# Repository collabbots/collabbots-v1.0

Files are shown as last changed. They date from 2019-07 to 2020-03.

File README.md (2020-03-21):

# collabbots-v1.0



Pictures of the setup (July 2019):
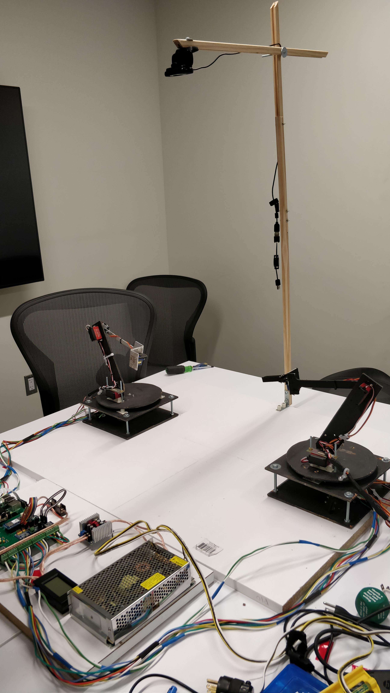
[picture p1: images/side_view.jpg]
side_view

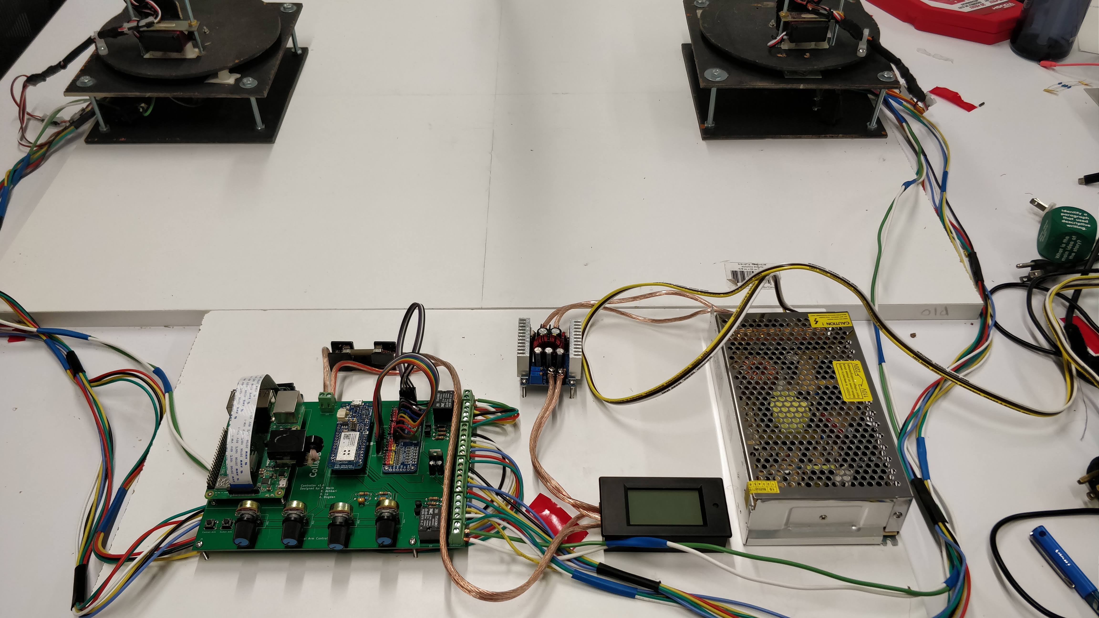
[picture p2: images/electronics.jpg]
electronics

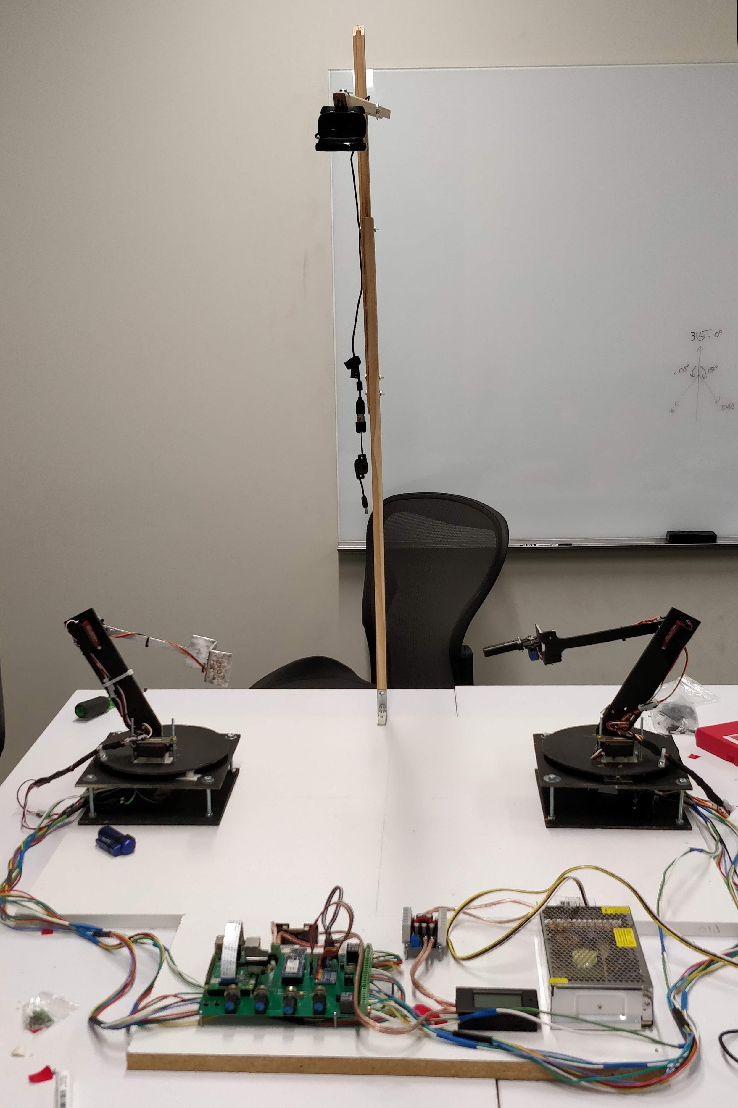
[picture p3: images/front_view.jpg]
front_view


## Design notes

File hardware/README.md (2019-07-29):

# hardware
Wiring diagrams, PCBs, and CAD files for the robots' hardware

**Controller PCB**
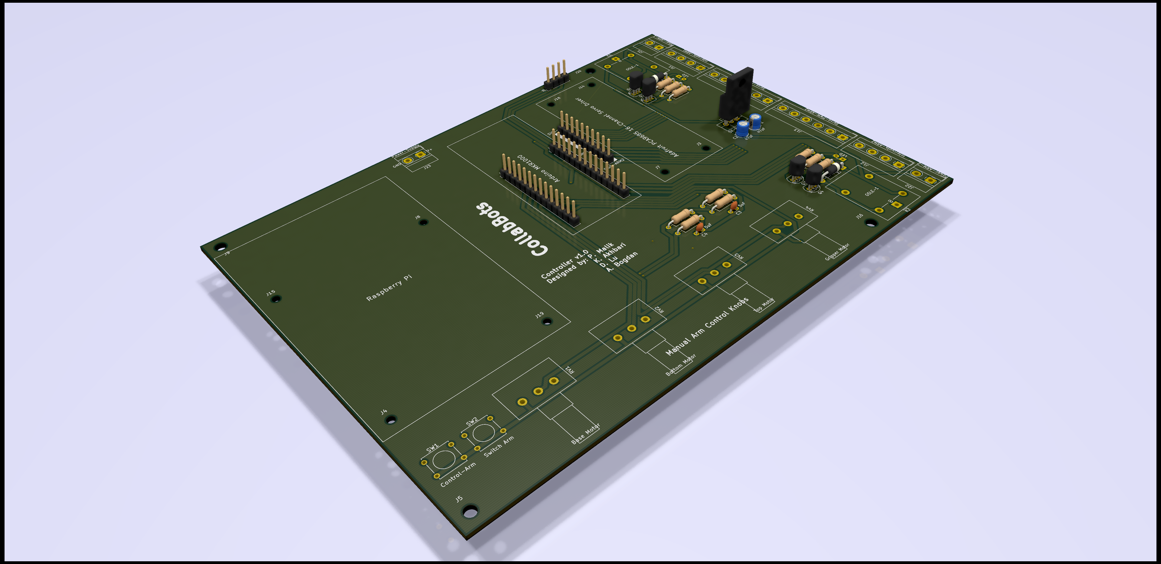
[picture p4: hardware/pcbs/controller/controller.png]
controller


**Connection Portal PCB**
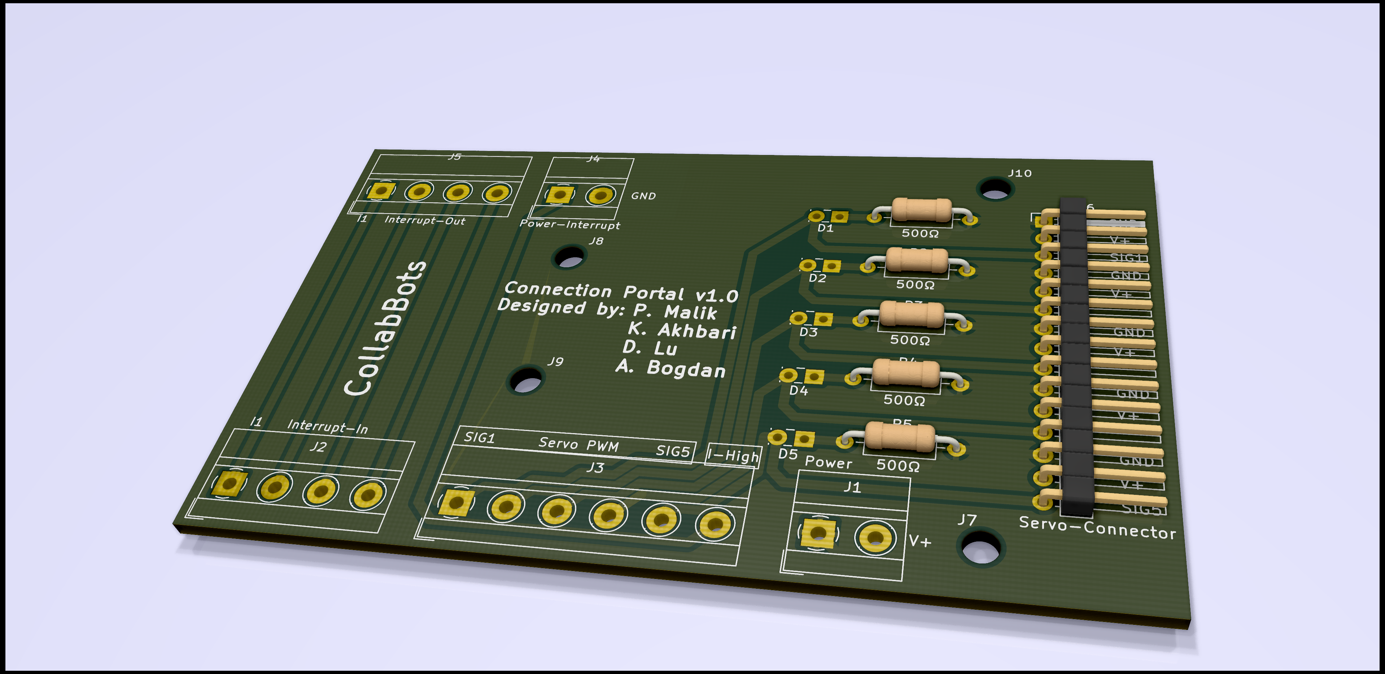
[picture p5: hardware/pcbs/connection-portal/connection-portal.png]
connection-portal


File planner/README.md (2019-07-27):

# planner
Plans and controls the tasks each robot has to perform to achieve its goal, based on inputs from the vision module.
1. The kinematics module solves the forward and inverse kinematics for the 3DOF Collabbots arm. It also handles visualization 
of the arm state.
2. The trajectory module solves/updates the trajectory for an arm  on the fly (real-time) based on inputs about obstacles in space from the vision module, with predictive planning of dynamic obstacles like another robotic arm. This module does not need or take information about the other arm(s) from the driver or kinematics module, and is just based on vision for that purpose.
3. The visualization module displays the current state of the system, the planned trajectories of the robotic arms, and status of the structure being built by the robots.

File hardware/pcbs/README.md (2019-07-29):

**Lessons learned**

Possible improvements for v2.0/v1.0 Rev B of the pcbs:

1. Reverse voltage protection using power PMOS, [zener, resistor (and LED for indication)]. **(vv important)**
2. integration of PCA9685 circuit into the pcb itself: reduce form factor and external wiring. **(vv important)**
3. For the connection portal pcb: the interrupt wires have to currently be all powered through one I-High and GND port. Rather have an array of 3 jumpers: interrupt, power, GND so that it is easier to wire and manage micro/limit switches. **(important)**
4. Use bigger (appropriately sized) vias -- comparable to the track thickness
5. Make the LED circuits brighter -- use transistors
6. Make an enclosure for the pcbs, with place for the knobs to come out.
7. Properly label all connections and components on the pcb (both sides for clarity and ease of use)
8. The number of motors is 4, but the connection portal and controller have capacity and connections for 5. This is a mismatch; keep the limit of motors to 4 if the arm design remains the same.
9. Have a port for the switch, which will interrupt the input power. This can be done by having a mount for a fuse between the switch and input power, so that traces don't have to be very thick and instead GND can go through the fuse from the switch. **(vv important)**
10. Have a dedicated place to mount the buck converter output fuse on the controller which could be a thick screw terminal, maybe. **(important)** 
11. The V+ and GND plates act like a capacitor and is dangerous for sensitive equipment or devices monitoring V+ since even after cutting the supply, V+ is floating at 1.5V or higher. Design circuitry to discharge this without overloading the supply and overheating when switched on. **(important)**
12. Arrange the terminal block for the two arms so that it is easier to wire them. one on left and the other on right.
13. Can mount the RPi on the bottom, thereby reducing the PCB footprint by a lot, and also allowing enough space for routing cables for the RPi.
14. Try using SMD components to further reduce the footprint.
15. Can have LED indicators for all the wires for visual debugging and also. Use the on-board 5V supply for that.
16. Try redesigning the pcb such that the design is completely modular. Another controller pcb can add two more arms at maximum. Therefore removing RPi from the board and having it has an optional mount is one step towards achieving this. **(vvv important)**
17. Servo zero set correction circuitry (try adding large capacitors on the output -- make sure to avoid high current surges). **(vv important)**
18. The connection portal will not be necessary if we handle each robot using a small microcontroller. This will also enable parallel control. So, just a USB cable and power supply goes into the robot -- also reduces wiring tremendously.
19. There can be a USB interface board that handles distributing serial commands to multiple robots. So, from a single USB port of the RPi/computer, you have a command handler PCB connected to multiple robots through USB ports. This will promote expandibility of the system.

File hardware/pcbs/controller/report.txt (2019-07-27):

Info: Processing component “J19:/5D1BA1C7:MountingHole:MountingHole_2.2mm_M2”.
Info: Processing component “Q3:/5D0CD34E:Package_TO_SOT_THT:TO-92_Inline”.
Info: Processing component “Q2:/5D0ABB15:Package_TO_SOT_THT:TO-92_Inline”.
Info: Processing component “Q1:/5D03D092:Package_TO_SOT_THT:TO-92_Inline”.
Info: Processing component “K2:/5D0CD348:Relay_THT:Relay_SPDT_Omron-G5LE-1”.
Info: Processing component “K1:/5D09949D:Relay_THT:Relay_SPDT_Omron-G5LE-1”.
Info: Processing component “J22:/5D17306D:TerminalBlock_MetzConnect:TerminalBlock_MetzConnect_Type011_RT05502HBWC_1x02_P5.00mm_Horizontal”.
Info: Processing component “J21:/5D03C864:TerminalBlock_MetzConnect:TerminalBlock_MetzConnect_Type011_RT05502HBWC_1x02_P5.00mm_Horizontal”.
Info: Processing component “J20:/5D1C3773:MountingHole:MountingHole_3.2mm_M3”.
Info: Processing component “Q4:/5D0CD33C:Package_TO_SOT_THT:TO-92_Inline”.
Info: Processing component “J18:/5D1B0969:MountingHole:MountingHole_2.2mm_M2”.
Info: Processing component “J17:/5D10BA03:Connector_PinHeader_2.54mm:PinHeader_1x10_P2.54mm_Vertical”.
Info: Processing component “J16:/5D1C1334:MountingHole:MountingHole_3.2mm_M3”.
Info: Processing component “J15:/5D1B7D51:MountingHole:MountingHole_2.2mm_M2”.
Info: Processing component “J14:/5D1AE1C4:MountingHole:MountingHole_2.2mm_M2”.
Info: Processing component “J13:/5D195D9E:TerminalBlock_MetzConnect:TerminalBlock_MetzConnect_Type011_RT05506HBWC_1x06_P5.00mm_Horizontal”.
Info: Processing component “J12:/5D16642E:TerminalBlock_MetzConnect:TerminalBlock_MetzConnect_Type011_RT05504HBWC_1x04_P5.00mm_Horizontal”.
Info: Processing component “R8:/5D1610A8:Resistor_THT:R_Axial_DIN0207_L6.3mm_D2.5mm_P10.16mm_Horizontal”.
Info: Processing component “SW2:/5D1610C0:Button_Switch_THT:SW_Tactile_Straight_KSL0Axx1LFTR”.
Info: Processing component “SW1:/5D25172B:Button_Switch_THT:SW_Tactile_Straight_KSL0Axx1LFTR”.
Info: Processing component “RV4:/5D0DCB00:Potentiometer_THT:Potentiometer_Alps_RK163_Single_Horizontal”.
Info: Processing component “RV3:/5D0DDD8A:Potentiometer_THT:Potentiometer_Alps_RK163_Single_Horizontal”.
Info: Processing component “RV2:/5D0DBCBA:Potentiometer_THT:Potentiometer_Alps_RK163_Single_Horizontal”.
Info: Processing component “RV1:/5D050ABA:Potentiometer_THT:Potentiometer_Alps_RK163_Single_Horizontal”.
Info: Processing component “R10:/5D12BD6F:Resistor_THT:R_Axial_DIN0207_L6.3mm_D2.5mm_P10.16mm_Horizontal”.
Info: Processing component “R9:/5D135C93:Resistor_THT:R_Axial_DIN0207_L6.3mm_D2.5mm_P10.16mm_Horizontal”.
Info: Processing component “J11:/5D15F505:TerminalBlock_MetzConnect:TerminalBlock_MetzConnect_Type011_RT05504HBWC_1x04_P5.00mm_Horizontal”.
Info: Processing component “R7:/5D17BC5B:Resistor_THT:R_Axial_DIN0207_L6.3mm_D2.5mm_P10.16mm_Horizontal”.
Info: Processing component “R6:/5D0CD35A:Resistor_THT:R_Axial_DIN0207_L6.3mm_D2.5mm_P10.16mm_Horizontal”.
Info: Processing component “R5:/5D0CD336:Resistor_THT:R_Axial_DIN0207_L6.3mm_D2.5mm_P10.16mm_Horizontal”.
Info: Processing component “R4:/5D0CD354:Resistor_THT:R_Axial_DIN0207_L6.3mm_D2.5mm_P10.16mm_Horizontal”.
Info: Processing component “R3:/5D0AFA57:Resistor_THT:R_Axial_DIN0207_L6.3mm_D2.5mm_P10.16mm_Horizontal”.
Info: Processing component “R2:/5D03C157:Resistor_THT:R_Axial_DIN0207_L6.3mm_D2.5mm_P10.16mm_Horizontal”.
Info: Processing component “R1:/5D0ACEB4:Resistor_THT:R_Axial_DIN0207_L6.3mm_D2.5mm_P10.16mm_Horizontal”.
Info: Processing component “J10:/5D191D71:TerminalBlock_MetzConnect:TerminalBlock_MetzConnect_Type011_RT05506HBWC_1x06_P5.00mm_Horizontal”.
Info: Processing component “C1:/5D0EA149:Capacitor_THT:CP_Radial_D4.0mm_P1.50mm”.
Info: Processing component “C2:/5D0EABFE:Capacitor_THT:CP_Radial_D4.0mm_P1.50mm”.
Info: Processing component “C3:/5D1610C6:Capacitor_THT:C_Disc_D3.0mm_W1.6mm_P2.50mm”.
Info: Processing component “C4:/5D11BE1B:”.
Info: Processing component “D1:/5D03DCB9:Diode_THT:D_DO-41_SOD81_P10.16mm_Horizontal”.
Info: Processing component “D2:/5D03B8C7:LED_THT:LED_Rectangular_W3.9mm_H1.8mm_FlatTop”.
Info: Processing component “D3:/5D0CD342:Diode_THT:D_DO-41_SOD81_P10.16mm_Horizontal”.
Info: Processing component “D4:/5D0CD330:LED_THT:LED_Rectangular_W3.9mm_H1.8mm_FlatTop”.
Info: Processing component “J1:/5D042CD9:Connector_PinHeader_2.54mm:PinHeader_1x14_P2.54mm_Vertical”.
Info: Processing component “J2:/5D044DCC:Connector_PinHeader_2.54mm:PinHeader_1x14_P2.54mm_Vertical”.
Info: Processing component “5V-Regulator1:/5D0E8236:Package_TO_SOT_THT:TO-220F-3_Vertical”.
Info: Processing component “J9:/5D1BC6B0:MountingHole:MountingHole_3.2mm_M3”.
Info: Processing component “J8:/5D1B31C7:MountingHole:MountingHole_2.2mm_M2”.
Info: Processing component “J7:/5D0F0557:MountingHole:MountingHole_2.2mm_M2”.
Info: Processing component “J6:/5D1F4AF5:Connector_PinHeader_2.54mm:PinHeader_1x04_P2.54mm_Vertical”.
Info: Processing component “J5:/5D1BEE64:MountingHole:MountingHole_3.2mm_M3”.
Info: Processing component “J4:/5D1B584A:MountingHole:MountingHole_2.2mm_M2”.
Info: Processing component “J3:/5D0F0551:MountingHole:MountingHole_2.2mm_M2”.
Reconnect J2 pin 14 from 5V to D6.
Reconnect J2 pin 1 from D6 to 5V.
Reconnect J2 pin 2 from D7 to VIN.
Reconnect J2 pin 3 from D8-MOSI to Vcc.
Reconnect J2 pin 13 from VIN to D7.
Reconnect J2 pin 12 from Vcc to D8-MOSI.
Reconnect J2 pin 11 from GND to D9-SCK.
Reconnect J2 pin 10 from RESET to D10-MISO.
Reconnect J2 pin 9 from D14-Tx to D11-SDA.
Reconnect J2 pin 8 from D13-Rx to D12-SCL.
Reconnect J2 pin 7 from D12-SCL to D13-Rx.
Reconnect J2 pin 6 from D11-SDA to D14-Tx.
Reconnect J2 pin 5 from D10-MISO to RESET.
Reconnect J2 pin 4 from D9-SCK to GND.

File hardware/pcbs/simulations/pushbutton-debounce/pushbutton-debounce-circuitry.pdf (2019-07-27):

PWL(0 0 0.2 0 0.2009 2 0.2015 3.3 0.2020 2 0.2025 0 0.3 0 0.3001 3.3 0.4 3.3 0.5 3.3 0.6 3.3 0.7 3.3 1 3.3)

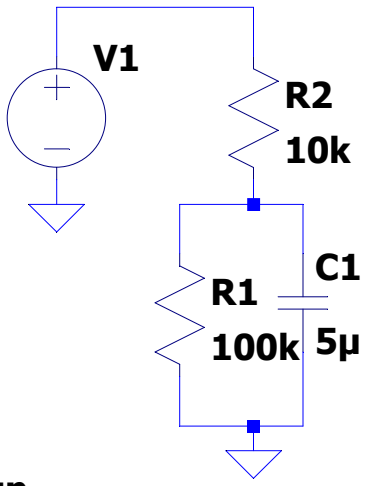
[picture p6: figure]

### .tran 0 0.5 0.19 startup

--- E:\1. Undergraduate Studies\3. Hackathons and Projects\3. Collaborations\CollabBots\hardware\pcbs\simulations\pushbutton-debounce\pushbutton-debounce-circuitry.asc ---

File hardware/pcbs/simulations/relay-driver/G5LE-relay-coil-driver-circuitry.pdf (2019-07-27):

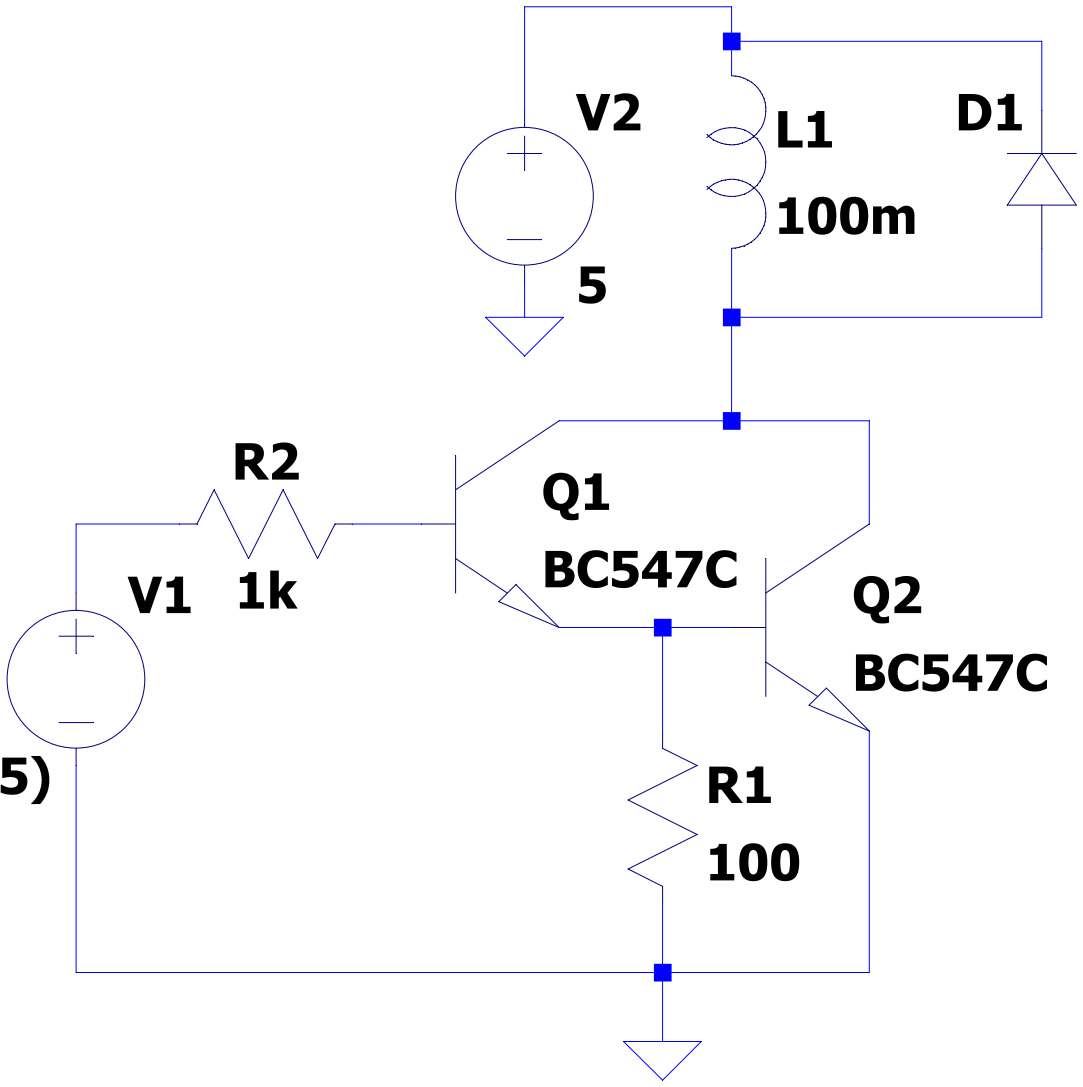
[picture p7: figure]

# PULSE(0 3.3 0 0 0 0.5 1 5)

1N4148

# .tran 0 5 0 startup

--- E:\1. Undergraduate Studies\3. Hackathons and Projects\3. Collaborations\CollabBots\hardware\pcbs\simulations\relay-driver\G5LE-relay-coil-driver-circuitry.asc ---

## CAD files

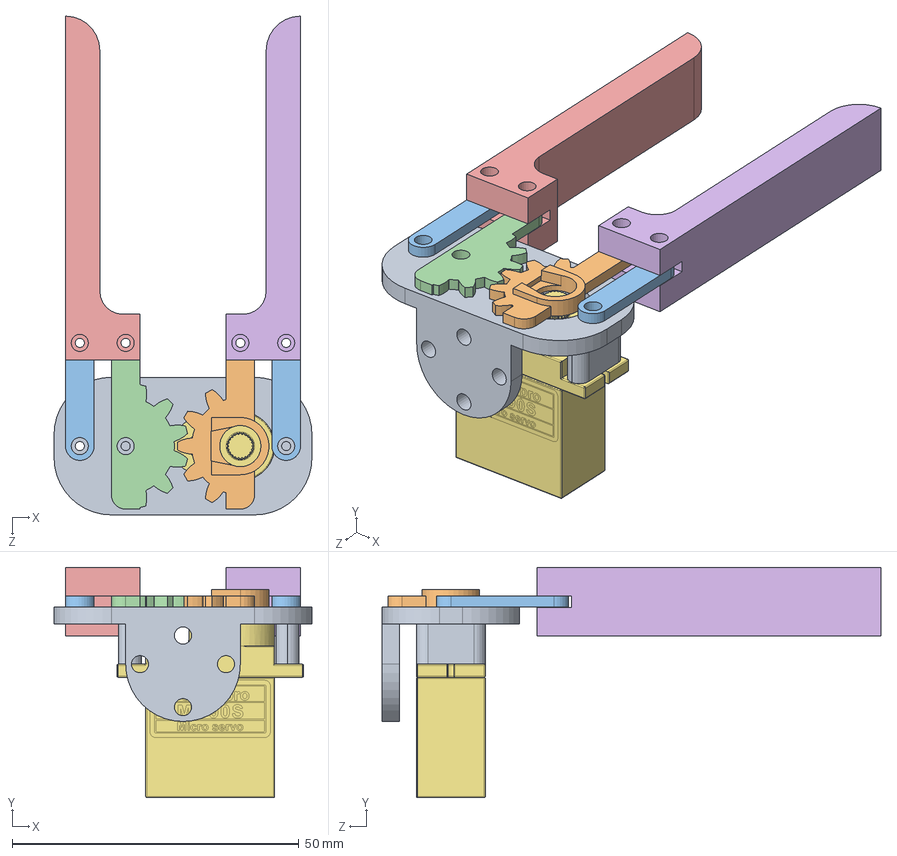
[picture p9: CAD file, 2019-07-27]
hardware/mech/gripper/assembly.SLDASM
45.0 x 40.2 x 87.0 mm
gripper_base
gear_2
bar_1 x 2
gear_1
finger_L
finger_R
micro_servo

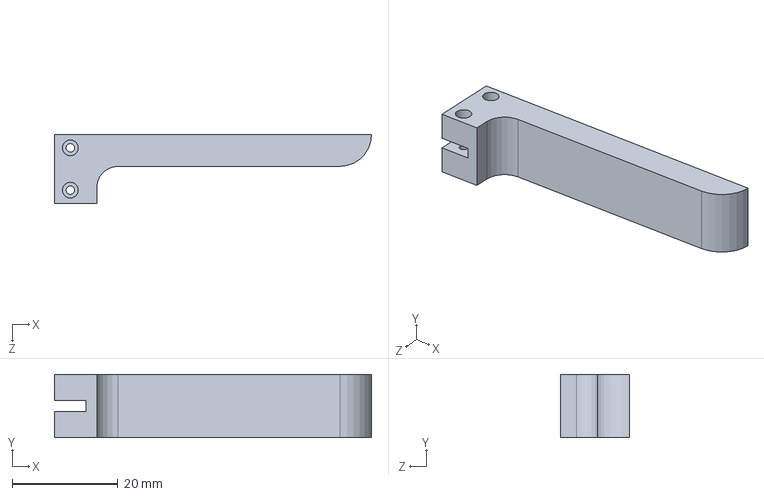
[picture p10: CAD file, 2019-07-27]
hardware/mech/gripper/finger_L.SLDPRT
60.0 x 12.0 x 13.0 mm

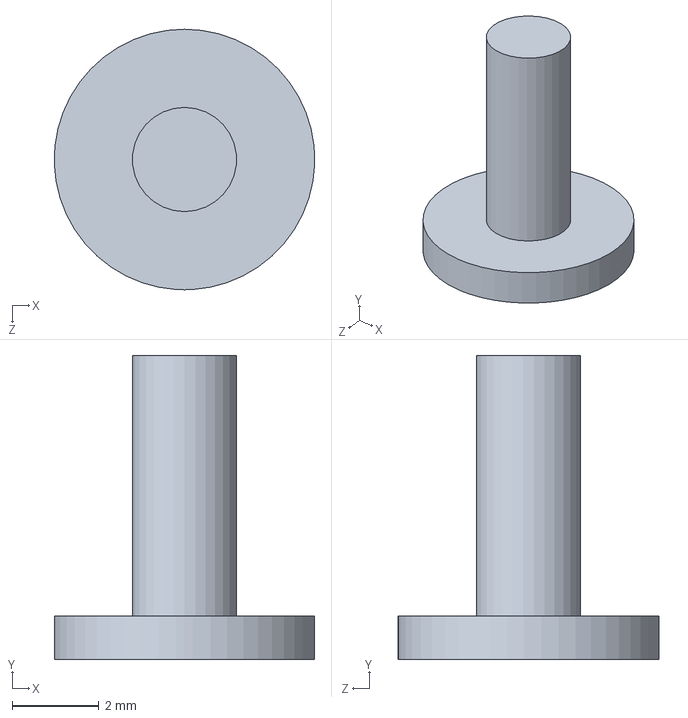
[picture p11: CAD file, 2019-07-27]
hardware/mech/gripper/axe_1.SLDPRT
6.00 x 7.00 x 6.00 mm

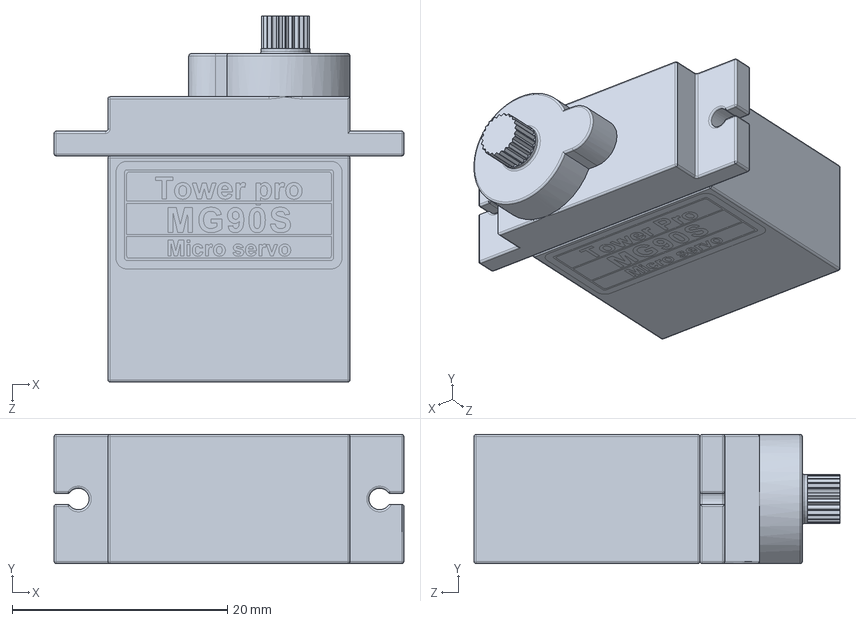
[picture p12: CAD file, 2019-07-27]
hardware/mech/gripper/micro_servo.SLDPRT
32.5 x 12.0 x 34.0 mm

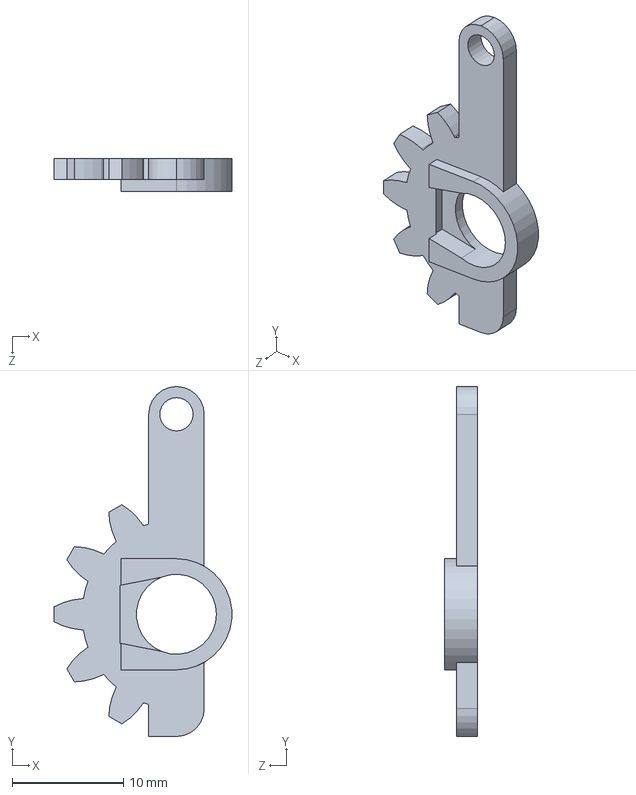
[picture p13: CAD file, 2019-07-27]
hardware/mech/gripper/gear_2.SLDPRT
16.0 x 31.5 x 3.00 mm

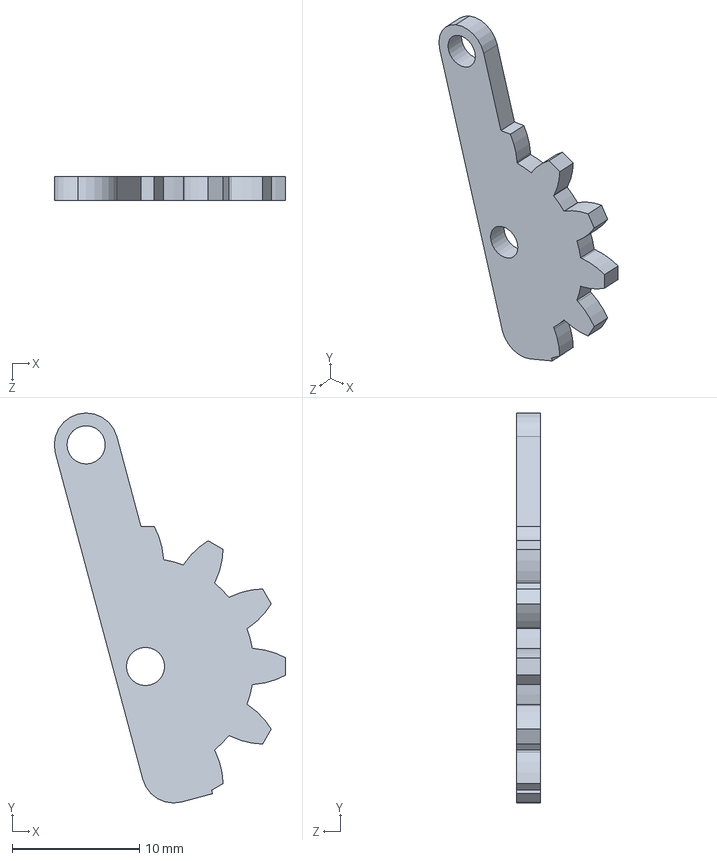
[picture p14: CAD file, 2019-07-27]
hardware/mech/gripper/gear_1.SLDPRT
18.2 x 30.6 x 1.90 mm

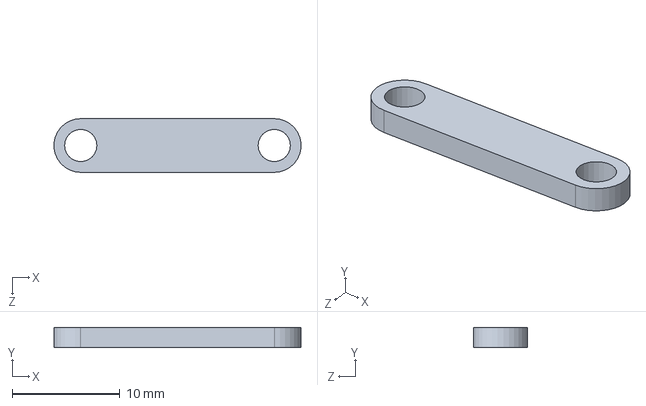
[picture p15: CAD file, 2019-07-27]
hardware/mech/gripper/bar_1.SLDPRT
23.0 x 1.90 x 5.00 mm

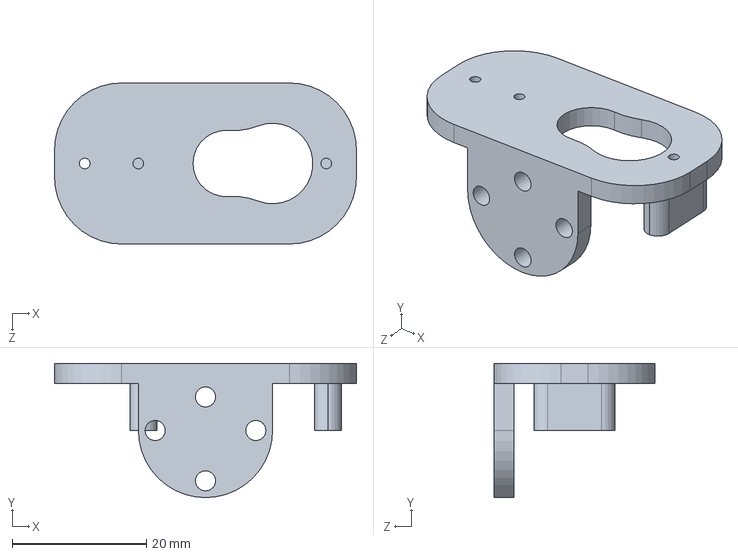
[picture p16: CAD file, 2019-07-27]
hardware/mech/gripper/gripper_base.SLDPRT
45.0 x 20.0 x 24.0 mm

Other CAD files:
hardware/mech/gripper/finger_R.SLDPRT

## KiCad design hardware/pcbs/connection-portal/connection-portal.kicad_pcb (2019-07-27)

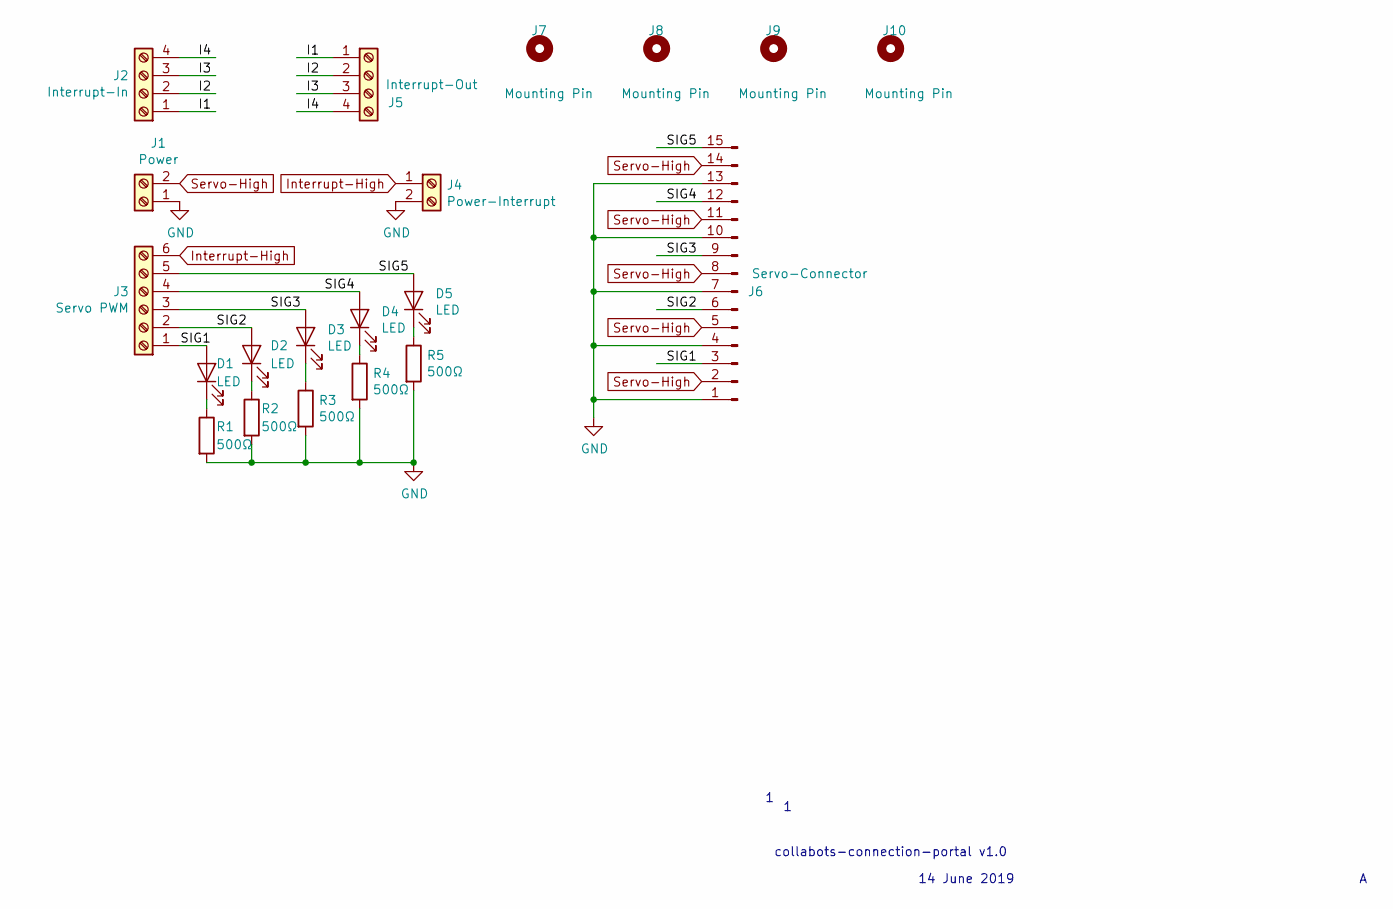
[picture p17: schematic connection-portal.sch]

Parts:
D1, D2, D3, D4, D5: LED; LED_Rectangular_W3.9mm_H1.8mm_FlatTop
J1: Power; TerminalBlock_MetzConnect_Type011_RT05502HBWC_1x02_P5.00mm_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
J2: Interrupt-In; TerminalBlock_MetzConnect_Type011_RT05504HBWC_1x04_P5.00mm_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
J3: Servo PWM; TerminalBlock_MetzConnect_Type011_RT05506HBWC_1x06_P5.00mm_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
J4: Power-Interrupt; TerminalBlock_MetzConnect_Type011_RT05502HBWC_1x02_P5.00mm_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
J5: Interrupt-Out; TerminalBlock_MetzConnect_Type011_RT05504HBWC_1x04_P5.00mm_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
J6: Servo-Connector; PinHeader_1x15_P2.54mm_Horizontal
J7, J8, J9, J10: Mounting Pin; MountingHole_3.2mm_M3
R1, R2, R3, R4, R5: 500Ω; R_Axial_DIN0207_L6.3mm_D2.5mm_P10.16mm_Horizontal

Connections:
/I1: J2.1, J5.1
/I2: J2.2, J5.2
/I3: J2.3, J5.3
/I4: J2.4, J5.4
/SIG1: D1.2 (A), J3.1, J6.3
/SIG2: D2.2 (A), J3.2, J6.6
/SIG3: D3.2 (A), J3.3, J6.9
/SIG4: D4.2 (A), J3.4, J6.12
/SIG5: D5.2 (A), J3.5, J6.15
GND: J1.1, J4.2, J6.1, J6.4, J6.7, J6.10, J6.13, R1.2, R2.2, R3.2, R4.2, R5.2
Interrupt-High: J3.6, J4.1
unnamed: D1.1 (K), R1.1
unnamed: D2.1 (K), R2.1
unnamed: D3.1 (K), R3.1
unnamed: D4.1 (K), R4.1
unnamed: D5.1 (K), R5.1
Servo-High: J1.2, J6.2, J6.5, J6.8, J6.11, J6.14

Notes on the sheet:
collabots-connection-portal v1.0
14 June 2019

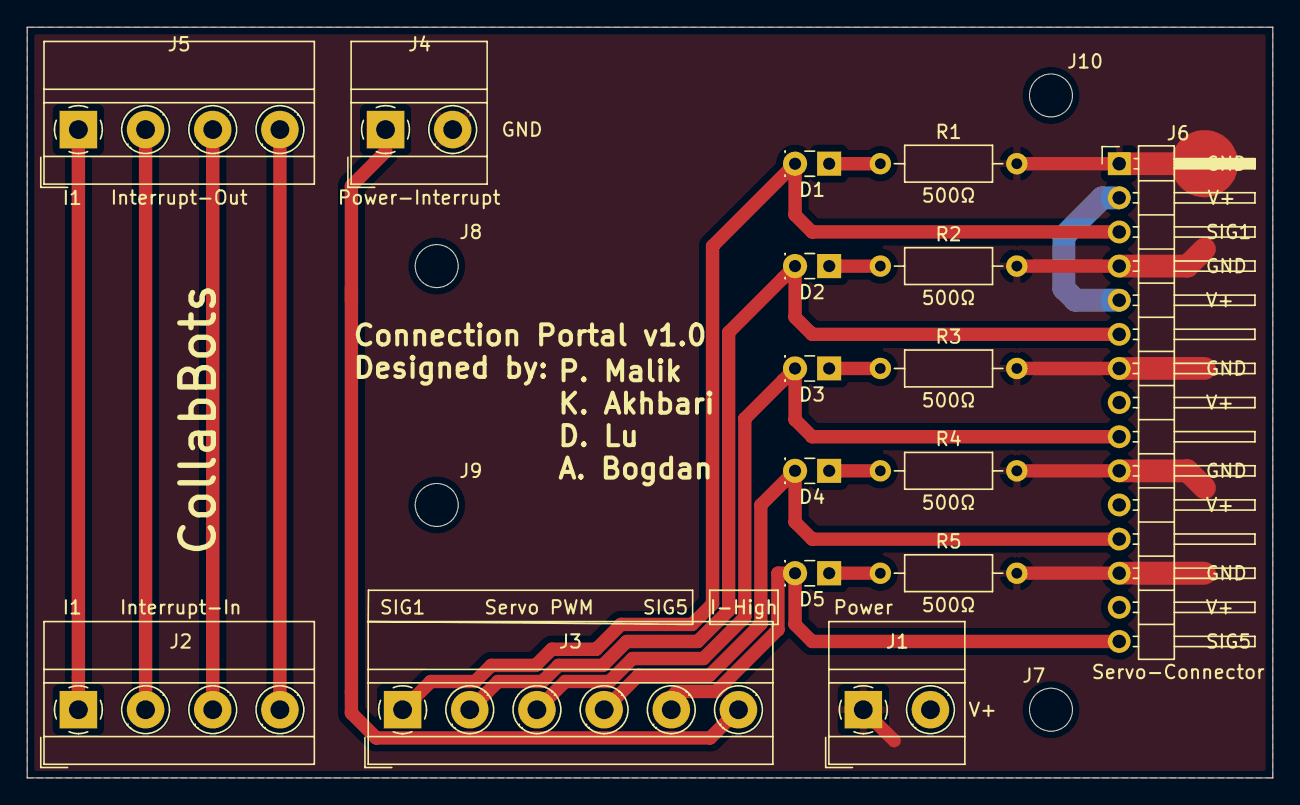
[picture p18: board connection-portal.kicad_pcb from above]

Board: 2 copper layers, 92.7 x 55.9 mm, 20 parts (0 on the bottom side), 17 nets.

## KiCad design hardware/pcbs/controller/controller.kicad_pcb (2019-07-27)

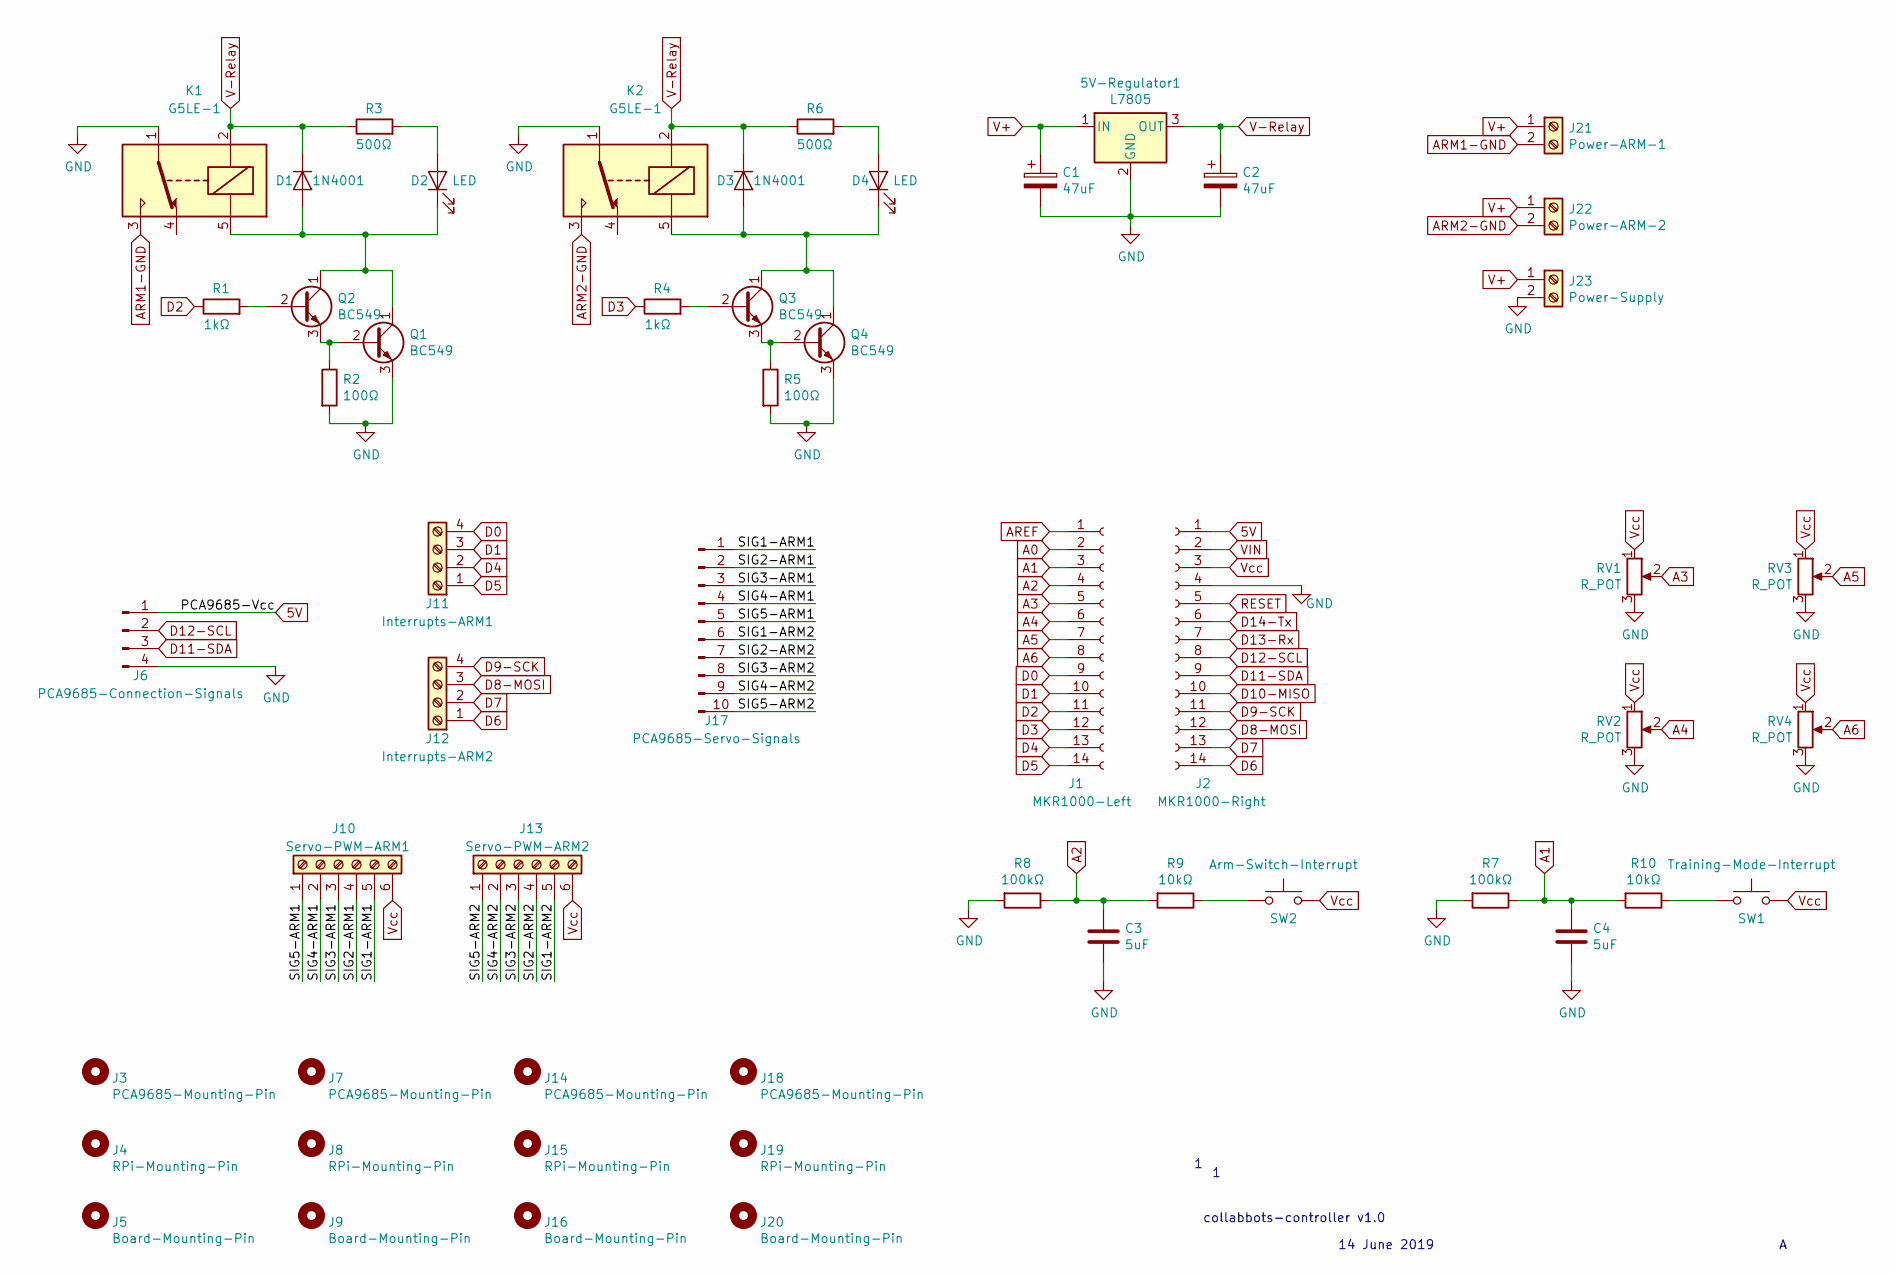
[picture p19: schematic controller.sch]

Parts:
5V-Regulator1: L7805; TO-220F-3_Vertical
C1, C2: 47uF; CP_Radial_D4.0mm_P1.50mm
C3: 5uF; C_Disc_D3.0mm_W1.6mm_P2.50mm
C4: 5uF
D1, D3: 1N4001; D_DO-41_SOD81_P10.16mm_Horizontal
D2, D4: LED; LED_Rectangular_W3.9mm_H1.8mm_FlatTop
J1: MKR1000-Left; PinHeader_1x14_P2.54mm_Vertical
J2: MKR1000-Right; PinHeader_1x14_P2.54mm_Vertical
J3, J7, J14, J18: PCA9685-Mounting-Pin; MountingHole_2.2mm_M2
J4, J8, J15, J19: RPi-Mounting-Pin; MountingHole_2.2mm_M2
J5, J9, J16, J20: Board-Mounting-Pin; MountingHole_3.2mm_M3
J6: PCA9685-Connection-Signals; PinHeader_1x04_P2.54mm_Vertical
J10: Servo-PWM-ARM1; TerminalBlock_MetzConnect_Type011_RT05506HBWC_1x06_P5.00mm_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
J11: Interrupts-ARM1; TerminalBlock_MetzConnect_Type011_RT05504HBWC_1x04_P5.00mm_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
J12: Interrupts-ARM2; TerminalBlock_MetzConnect_Type011_RT05504HBWC_1x04_P5.00mm_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
J13: Servo-PWM-ARM2; TerminalBlock_MetzConnect_Type011_RT05506HBWC_1x06_P5.00mm_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
J17: PCA9685-Servo-Signals; PinHeader_1x10_P2.54mm_Vertical
J21: Power-ARM-1; TerminalBlock_MetzConnect_Type011_RT05502HBWC_1x02_P5.00mm_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
J22: Power-ARM-2; TerminalBlock_MetzConnect_Type011_RT05502HBWC_1x02_P5.00mm_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
J23: Power-Supply; TerminalBlock_MetzConnect_Type011_RT05502HBWC_1x02_P5.00mm_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
K1, K2: G5LE-1; Relay_SPDT_Omron-G5LE-1
Q1, Q2, Q3, Q4: BC549; TO-92_Inline
R1, R4: 1kΩ; R_Axial_DIN0207_L6.3mm_D2.5mm_P10.16mm_Horizontal
R2, R5: 100Ω; R_Axial_DIN0207_L6.3mm_D2.5mm_P10.16mm_Horizontal
R3, R6: 500Ω; R_Axial_DIN0207_L6.3mm_D2.5mm_P10.16mm_Horizontal
R7, R8: 100kΩ; R_Axial_DIN0207_L6.3mm_D2.5mm_P10.16mm_Horizontal
R9, R10: 10kΩ; R_Axial_DIN0207_L6.3mm_D2.5mm_P10.16mm_Horizontal
RV1, RV2, RV3, RV4: R_POT; Potentiometer_Alps_RK163_Single_Horizontal
SW1: Training-Mode-Interrupt; SW_Tactile_Straight_KSL0Axx1LFTR
SW2: Arm-Switch-Interrupt; SW_Tactile_Straight_KSL0Axx1LFTR

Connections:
5V: J2.1, J6.1
/SIG1-ARM1: J10.5, J17.1
/SIG1-ARM2: J13.5, J17.6
/SIG2-ARM1: J10.4, J17.2
/SIG2-ARM2: J13.4, J17.7
/SIG3-ARM1: J10.3, J17.3
/SIG3-ARM2: J13.3, J17.8
/SIG4-ARM1: J10.2, J17.4
/SIG4-ARM2: J13.2, J17.9
/SIG5-ARM1: J10.1, J17.5
/SIG5-ARM2: J13.1, J17.10
A0: J1.2
A1: C4.1, J1.3, R7.1, R10.2
A2: C3.1, J1.4, R8.1, R9.2
A3: J1.5, RV1.2
A4: J1.6, RV2.2
A5: J1.7, RV3.2
A6: J1.8, RV4.2
AREF: J1.1
ARM1-GND: J21.2, K1.3
ARM2-GND: J22.2, K2.3
D0: J1.9, J11.4
D1: J1.10, J11.3
D2: J1.11, R1.1
D3: J1.12, R4.1
D4: J1.13, J11.2
D5: J1.14, J11.1
D6: J2.14, J12.1
D7: J2.13, J12.2
D8-MOSI: J2.12, J12.3
D9-SCK: J2.11, J12.4
D10-MISO: J2.10
D11-SDA: J2.9, J6.3
D12-SCL: J2.8, J6.2
D13-Rx: J2.7
D14-Tx: J2.6
GND: 5V-Regulator1.2 (GND), C1.2, C2.2, C3.2, C4.2, J2.4, J6.4, J23.2, K1.1, K2.1, Q1.3 (E), Q4.3 (E), R2.2, R5.2, R7.2, R8.2, RV1.3, RV2.3, RV3.3, RV4.3
unnamed: D1.2 (A), D2.1 (K), K1.5, Q1.1 (C), Q2.1 (C)
unnamed: D2.2 (A), R3.2
unnamed: D3.2 (A), D4.1 (K), K2.5, Q3.1 (C), Q4.1 (C)
unnamed: D4.2 (A), R6.2
unnamed: Q1.2 (B), Q2.3 (E), R2.1
unnamed: Q2.2 (B), R1.2
unnamed: Q3.2 (B), R4.2
unnamed: Q3.3 (E), Q4.2 (B), R5.1
unnamed: R9.1, SW2.1
unnamed: R10.1, SW1.1
RESET: J2.5
V+: 5V-Regulator1.1 (IN), C1.1, J21.1, J22.1, J23.1
V-Relay: 5V-Regulator1.3 (OUT), C2.1, D1.1 (K), D3.1 (K), K1.2, K2.2, R3.1, R6.1
VIN: J2.2
Vcc: J2.3, J10.6, J13.6, RV1.1, RV2.1, RV3.1, RV4.1, SW1.2, SW2.2

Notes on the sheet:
collabbots-controller v1.0
14 June 2019

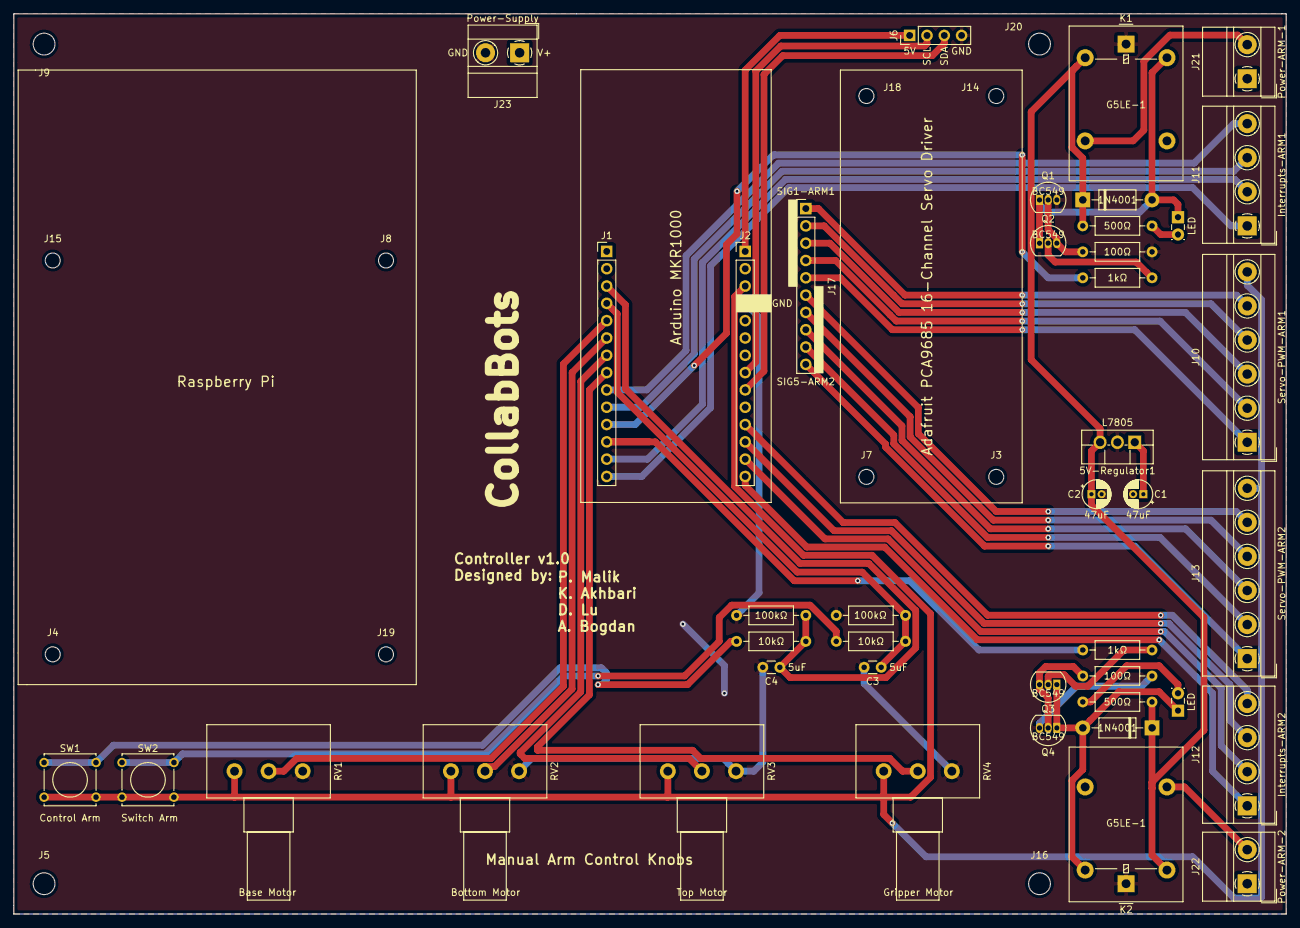
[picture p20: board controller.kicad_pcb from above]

Board: 2 copper layers, 186.7 x 132.1 mm, 54 parts (0 on the bottom side), 45 nets.

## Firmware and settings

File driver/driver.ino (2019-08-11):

#include "motor_control.h"
#include "wifi_rw.h"

// TODO: arm 1/2 relax disconnects power from the arm. activate will switch it back on.
// TODO: add wifi data transfer of angles for visualization module to work off the system.
// TODO: add manual control code and construct FSM for the same.
// TODO: organize code into multiple files.

/******************
   MAIN EXECUTION
 ******************/

void arm1Interrupt()
{
  sys_state = ARM_1_LIMIT_INTRPT;
}

void arm2Interrupt()
{
  sys_state = ARM_2_LIMIT_INTRPT;
}

void changeToManual()
{
  currentMode = MANUAL;
}

void changeToCommandLine()
{
  currentMode = COMMAND_LINE;
}

int input;
String stringInput; 
String armToChange;
String motorToChange;
int amountToChange;

void setup()
{
  Serial.begin(9600);

  pinMode(2, OUTPUT);
  digitalWrite(2, HIGH);
  pinMode(3, OUTPUT);
  digitalWrite(3, HIGH);

  // configure interrupts
  pinMode(arm_1_bot_intrpt_1, INPUT_PULLUP);
  attachInterrupt(digitalPinToInterrupt(arm_1_bot_intrpt_1), arm1Interrupt, RISING);
  pinMode(arm_1_bot_intrpt_2, INPUT_PULLUP);
  attachInterrupt(digitalPinToInterrupt(arm_1_bot_intrpt_2), arm1Interrupt, RISING);
  pinMode(arm_1_top_intrpt_1, INPUT_PULLUP);
  attachInterrupt(digitalPinToInterrupt(arm_1_top_intrpt_1), arm1Interrupt, RISING);
  pinMode(arm_1_top_intrpt_2, INPUT_PULLUP);
  attachInterrupt(digitalPinToInterrupt(arm_1_top_intrpt_2), arm1Interrupt, RISING);
  pinMode(arm_2_bot_intrpt_1, INPUT_PULLUP);
  attachInterrupt(digitalPinToInterrupt(arm_2_bot_intrpt_1), arm2Interrupt, RISING);
  pinMode(arm_2_bot_intrpt_2, INPUT_PULLUP);
  attachInterrupt(digitalPinToInterrupt(arm_2_bot_intrpt_2), arm2Interrupt, RISING);
  pinMode(arm_2_top_intrpt_1, INPUT_PULLUP);
  attachInterrupt(digitalPinToInterrupt(arm_2_top_intrpt_1), arm2Interrupt, RISING);
  pinMode(arm_2_top_intrpt_2, INPUT_PULLUP);
  attachInterrupt(digitalPinToInterrupt(arm_2_top_intrpt_2), arm2Interrupt, RISING);
  pinMode(A1, INPUT_PULLUP);
  attachInterrupt(digitalPinToInterrupt(A1), changeToManual, RISING);
  pinMode(A2, INPUT_PULLUP);
  attachInterrupt(digitalPinToInterrupt(A2), changeToCommandLine, RISING);


  // configure starting positions for the motors
  pwm.begin();
  pwm.setPWMFreq(60); // analog servos run at ~60 Hz updates
  pwm.setPWM(arm_1_base_pin, 0, MINIMUM_PULSE);
  pwm.setPWM(arm_2_base_pin, 0, MINIMUM_PULSE);
  delay(500);
  pwm.setPWM(arm_1_bottom_pin, 0, 395);
  pwm.setPWM(arm_2_bottom_pin, 0, MINIMUM_PULSE);
  delay(500);
  pwm.setPWM(arm_1_top_pin, 0, 315);
  pwm.setPWM(arm_2_top_pin, 0, 315);
  pwm.setPWM(arm_1_claw_pin, 0, 160);
  pwm.setPWM(arm_2_claw_pin, 0, 160);
  delay(500);
}

void loop()
{

  /**********
   MANUAL MODE 
   In manual mode, run the serial monitor on Mac/Ubuntu and hold
   the keys to turn the arm. 
   A/D: rotate base 
   W/S: rotate bottom
   Q/E: rotate top 
   Z/C: open/close claw
   Note: lower case means controlling arm 1; CAPS LOCK means controlling arm 2
   **********/

  if (currentMode == MANUAL){
  
    // read input
    if (sys_state == REQ_INSTRCT)
    {
      sys_state = READ_INSTRCT;
    }
    else if (sys_state == READ_INSTRCT)
    {
      if (Serial.available() > 0)
      {
        input = Serial.read();
        // go onto to next state
        sys_state = EXECUTE_INSTRCT;
      }
    }
    else if (sys_state == EXECUTE_INSTRCT)
    {
      if (input == 'A')
        rotateBase(arm_2_base_angle + 3, ARM2);
  
      else if (input == 'D')
        rotateBase(arm_2_base_angle - 3, ARM2);
  
      else if (input == 'W')
        rotateBottom(arm_2_bottom_angle + 3, ARM2);
  
      else if (input == 'S')
        rotateBottom(arm_2_bottom_angle - 3, ARM2);
  
      else if (input == 'Q')
        rotateTop(arm_2_top_angle + 3, ARM2);
  
      else if (input == 'E')
        rotateTop(arm_2_top_angle - 3, ARM2);
  
      else if (input == 'Z')
        setClawSpacing(5, ARM2);
  
      else if (input == 'C')
        setClawSpacing(2, ARM2);
  
      else if (input == 'a')
        rotateBase(arm_1_base_angle + 3, ARM1);
  
      else if (input == 'd')
        rotateBase(arm_1_base_angle - 3, ARM1);
  
      else if (input == 'w')
        rotateBottom(arm_1_bottom_angle + 3, ARM1);
  
      else if (input == 's')
        rotateBottom(arm_1_bottom_angle - 3, ARM1);
  
      else if (input == 'q')
        rotateTop(arm_1_top_angle + 3, ARM1);
  
      else if (input == 'e')
        rotateTop(arm_1_top_angle - 3, ARM1);
  
      else if (input == 'z')
        setClawSpacing(5, ARM1);
  
      else if (input == 'c')
        setClawSpacing(2, ARM1);

      else if (input == '?'){
        relaysOn = !relaysOn; 
        if (relaysOn){
          digitalWrite(2, HIGH);
          digitalWrite(3, HIGH);
        }
        else{
          digitalWrite(2, LOW);
          digitalWrite(3, LOW);
        }

      }

      else if (input == '~'){
        currentMode = COMMAND_LINE;
        sys_state = REQ_INSTRCT; 
        return;  
      }
  
      sys_state = REQ_INSTRCT;
    }
    else if (sys_state == ARM_1_LIMIT_INTRPT)
    {
      rotateBottom(90, ARM1);
      rotateTop(0, ARM1);
      sys_state = REQ_INSTRCT;
    }
    else if (sys_state == ARM_2_LIMIT_INTRPT)
    {
      rotateBottom(90, ARM2);
      rotateTop(0, ARM2);
      sys_state = REQ_INSTRCT;
    }

  }

  /**********
   COMMAND_LINE MODE 
   In command line mode, enter the commands in the Serial monitor 
   to turn the arm to a specified position.
   Commands take the following form: 
   set arm1/arm2 base/bottom/top/claw angle/spacing
   **********/

  else if (currentMode == COMMAND_LINE){
    // read stringInput
    if (sys_state == REQ_INSTRCT)
    {
      Serial.println("Enter command in form: let arm1/arm2 base/bottom/top/claw angle/spacing");
      sys_state = READ_INSTRCT;
    }
    else if (sys_state == READ_INSTRCT) 
    {
      if (Serial.available() > 0) 
      {
        stringInput = Serial.readStringUntil('\n');
        // go onto to next state
        sys_state = PARSE_INSTRCT;
      }
    }
    else if (sys_state == PARSE_INSTRCT) 
    {
      if (stringInput[0] == '~'){
        currentMode = MANUAL; 
        sys_state = REQ_INSTRCT;
        return; 
      }
      // find location of spaces
      int firstSpace = -1;
      int secondSpace = -1;
      int thirdSpace = -1;
      for (int i = 0; i < stringInput.length(); i++) {
        if (stringInput[i] == ' ' && firstSpace == -1)
          firstSpace = i;
        else if (stringInput[i] == ' ' && secondSpace == -1)
          secondSpace = i;
        else if (stringInput[i] == ' ' && thirdSpace == -1)
          thirdSpace = i;
      }
  
      if (firstSpace != -1 && secondSpace != -1 && thirdSpace != -1) 
      {
        // break the string apart at the spaces
        armToChange = stringInput.substring(firstSpace + 1, secondSpace);
        motorToChange = stringInput.substring(secondSpace + 1, thirdSpace);
        String amountToChangeString = stringInput.substring(thirdSpace + 1, stringInput.length());
        amountToChange = amountToChangeString.toInt();
  
        sys_state = EXECUTE_INSTRCT;
      }
      else 
      {
        Serial.println("Sorry, invalid command");
        sys_state = REQ_INSTRCT;
      }
    }
    else if (sys_state == EXECUTE_INSTRCT) 
    {
      Serial.print("Setting "); 
      Serial.print(armToChange); 
      Serial.print(" "); 
      Serial.print(motorToChange); 
      Serial.print(" to "); 
      Serial.println(amountToChange);
  
      if (armToChange == "arm1")
      {
        if (motorToChange == "base")
          rotateBase(amountToChange, ARM1);
  
        if (motorToChange == "bottom")
          rotateBottom(amountToChange, ARM1);
  
        if (motorToChange == "top")
          rotateTop(amountToChange, ARM1);
  
        if (motorToChange == "claw")
          setClawSpacing(amountToChange, ARM1);
      }
      else if (armToChange == "arm2") 
      {
        if (motorToChange == "base")
          rotateBase(amountToChange, ARM2);
  
        if (motorToChange == "bottom")
          rotateBottom(amountToChange, ARM2);
  
        if (motorToChange == "top")
          rotateTop(amountToChange, ARM2);
  
        if (motorToChange == "claw")
          setClawSpacing(amountToChange, ARM2);
      }
  
      sys_state = REQ_INSTRCT;
    }
    else if (sys_state == ARM_1_LIMIT_INTRPT) 
    {
      rotateBottom(90, ARM1);
      rotateTop(0, ARM1);
      sys_state = REQ_INSTRCT;
    }
    else if (sys_state == ARM_2_LIMIT_INTRPT) 
    {
      rotateBottom(90, ARM2);
      rotateTop(0, ARM2);
      sys_state = REQ_INSTRCT;
    }
  }
  
}

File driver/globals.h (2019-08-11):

#ifndef globals_h
#define globals_h

#include <Adafruit_PWMServoDriver.h>

/****************************
  MODE OF OPERATION FOR ROBOT
 ****************************/

enum current_mode{
  // In command line mode, enter the commands in the Serial monitor 
  // to turn the arm to a specified position
  COMMAND_LINE, 

  // In manual mode, run the serial monitor on Mac/Ubuntu and hold
  // the keys to turn the arm
  MANUAL
}; 

current_mode currentMode = MANUAL;  


/********************
   GLOBAL VARIABLES
 ********************/

// servo drivers
Adafruit_PWMServoDriver pwm = Adafruit_PWMServoDriver();
uint8_t servonum = 1;

// minimum/maximum pulse signals
#define MINIMUM_PULSE 90
#define MAXIMUM_PULSE 540

// two arms
#define ARM1 1
#define ARM2 2

// finite system states to implement robot interface as an FSM (Finite State Machine) 
enum system_state {
  REQ_INSTRCT,      // request for instruction
  READ_INSTRCT,     // read instruction
  PARSE_INSTRCT,    // parse instruction
  EXECUTE_INSTRCT,  // execute instruction
  ARM_1_LIMIT_INTRPT, //
  ARM_2_LIMIT_INTRPT, //
  MANUAL_CTRL_INTRPT, //
  ARM_SWITCH_INTRPT   //
};

system_state sys_state = REQ_INSTRCT;

// max/min angles for the different motors
#define MAX_TOP_ANGLE 135
#define MAX_BOTTOM_ANGLE 180
#define MAX_BASE_ANGLE 180
#define MIN_TOP_ANGLE -135
#define MIN_BOTTOM_ANGLE 0
#define MIN_BASE_ANGLE 0

// servo controller (PCA9685) pins for arm motors
const int arm_1_base_pin = 0;
const int arm_1_bottom_pin = 1;
const int arm_1_top_pin = 2;
const int arm_1_claw_pin = 3;
const int arm_2_base_pin = 5;
const int arm_2_bottom_pin = 6;
const int arm_2_top_pin = 7;
const int arm_2_claw_pin = 8;

// interrupt pins from the arms to thr MKR1000
const int arm_1_bot_intrpt_1 = 0;
const int arm_1_bot_intrpt_2 = 1;
const int arm_1_top_intrpt_1 = 4;
const int arm_1_top_intrpt_2 = 5;
const int arm_2_bot_intrpt_1 = 6;
const int arm_2_bot_intrpt_2 = 7;
const int arm_2_top_intrpt_1 = 8;
const int arm_2_top_intrpt_2 = 9;

// current angular position
int arm_1_base_angle = 0;
int arm_1_bottom_angle = 0;
int arm_1_top_angle = 0;
int arm_2_base_angle = 0;
int arm_2_bottom_angle = 0;
int arm_2_top_angle = 0;

// speed delay for motors (higher = slower)
const int motor_speed_delay = 25;

// controls whether relays are on or off
bool relaysOn = true; 

#endif

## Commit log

2019-07-27 making a single repository to hold all sub-components
    [assembly.SLDASM, axe_1.SLDPRT, bar_1.SLDPRT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]
2019-07-28 programmed serial input (can type to manually move arm)
2019-07-28 made the interface more user-friendly with feedback on what the arm is doing
2019-07-28 interrupts now work!
2019-07-29 added feedback on pcbs for future improvement
2019-07-29 reorganizing driver. also need to expand for manual control and wireless state data transfer
2019-08-02 dividing driver into multiple files to manage complexity
2019-08-03 redo of previous commit to correct update errors
    [driver.ino]
2019-08-04 configured interrupts to configure mode
2019-08-04 new cpp file to send input to the arduino
2019-08-11 introduced new way to switch between modes; changed and improved PS4 control to make it more ergonomic; enabled turning off relay wirelessly
2019-08-18 Pushing vision code - Camera and Filters
2019-08-18 fully implemented colour filtering in a new Vision class
2019-08-19 added test functions for calibration
